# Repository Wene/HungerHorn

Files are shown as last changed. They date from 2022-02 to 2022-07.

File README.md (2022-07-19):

# HungerHorn

Once upon a time in a hackerspace far far away, on a Tuesday, everyone got hungry. And so it was decided to go hunt for a Pizza. The next Tuesday after that, they all got hungry again. But this time not everyone was in for the hunt right away. Apparently it was too early. Last week, so some commented, they all went at 19:00 o'clock. But yet it was just 18:55.
As social as the common hacker is, everyone waited patiently for the remaining 5 minutes before the hunt could begin. From this time on, the tradition was established. HungerTime™ is at precisely 19:00 o'clock.

Since this story is about a hackerspace, we naturally need to solve everything with technical measures. And so the project HungerHorn™ got started. It's supposed to sound an alarm signal at precisely HunterTime™. Since, nobody needs to stare at a watch the exciting minutes before.

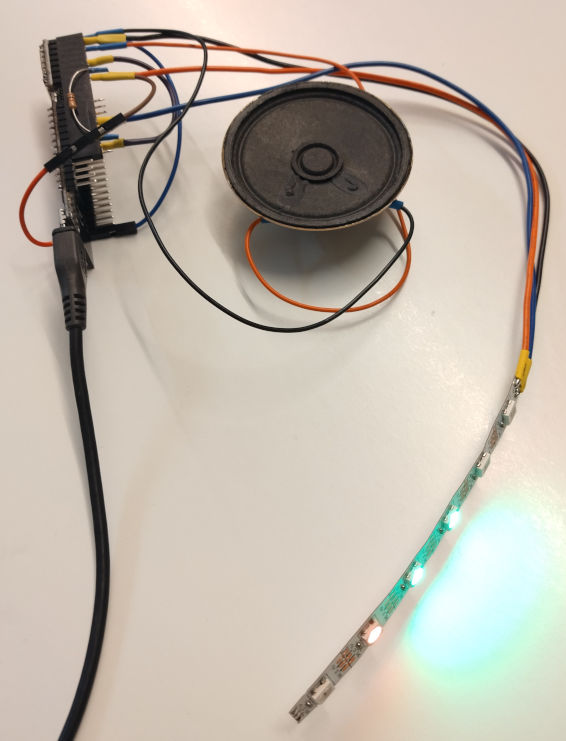
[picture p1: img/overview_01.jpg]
overview image


## Getting started

### Hardware
I'm using an ESP32 board called "WeMos LOLIN32 Lite". But any ESP32 should do. For the sound output a 0.3W PC speaker and a "DF Player mini" MP3 player module with a micro SD card is used. To display the time, I'm using a short strip of 6 WS2812B RGB LEDs.

### Software
The software is written using the PlatformIO toolkit. I use Qt Creator as source code editor, but I'm sure VS Code and others will also do.

After cloning the project, execute `platformio init --board lolin32_lite --ide qtcreator` in the project directory to initialize it. Adjust the command to your hardware board and IDE of choice. Then open the code in the `src/` directory and adjust the GPIOs or whatever needed for different hardware. Call `platformio run -t upload` to install it on your board.

### 3D Print
I've used the files in the `cad/` folder to 3D-print a case for the HungerHorn™. You will have to adjust several dimensions if you don't have exactly the same speaker and LED strip. To edit the 2D .dxf contours, I use LibreCAD. and the 3D models are OpenSCAD files.

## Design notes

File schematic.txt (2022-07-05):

┌─────────────────────────┬───────────────┐
│    ┌─────────┐          │               │
│  ┌─┤         ├───────┐  │  ┌──────────┐ │
│ ─┤ │         │  SPK2 ├──┼──┤ -        │ │
│  │ │ MicroSD │       │  │  │          │ │
│ ─┤ │         │   GND ├──┘  │  Speaker │ │
│  │ │         │       │     │          │ │
│ ─┤ │         │  SPK1 ├─────┤ +        │ │
│  │ └─────────┘       │     └──────────┘ │
│ ─┤                   ├─                 │
│  │ DF Player Mini    │               ┌──┘
│ ─┤                   ├─              │
│  │                   │               │
│ ─┤                TX ├────────────┐  │
│  │                   │            │  │
│ ─┤                RX ├───────┐    │  │
│  │                   │       │    │  │
│ ─┤               VCC ├──┐    │    │  │
│  └───────────────────┘  │ ┌──┴──┐ │  │
│                         │ │ 1kΩ │ │  │
│  ┌───────────────────┐  │ └──┬──┘ │  │
│ ─┤ VP            3v3 ├─ │    │    │  │
│  │                   │  │    │    │  │
│ ─┤ VN             22 ├─ │    │    │  │
│  │                   │  │    │    │  │ ┌─────────────────────────┐
│ ─┤ EN             19 ├─ │    │    │  └─┤ GND                     │
│  │      LOLIN32      │  │    │    │    │                         │
│ ─┤ 34   Lite      23 ├──┼────┼────┼────┤ DATA   6 × WS2812B LEDs │
│  │      ESP32        │  │    │    │    │                         │
│ ─┤ 35             18 ├─ ├────┼────┼────┤ 5V                      │
│  │                   │  │    │    │    └─────────────────────────┘
│ ─┤ 32              5 ├─ │    │    │
│  │                   │  │    │    │
│ ─┤ 33             17 ├──┼────┘    │
│  │                   │  │         │
│ ─┤ 25             16 ├──┼─────────┘
│  │                   │  │
│ ─┤ 26              4 ├─ │
│  │                   │  │
│ ─┤ 27              0 ├─ │
│  │                   │  │
│ ─┤ 14              2 ├─ │
│  │        5V         │  │
│ ─┤ 12     │       15 ├─ │
│  │        │          │  │
└──┤ GND    │       13 ├─ │
   └────────┼──────────┘  │
            └─────────────┘

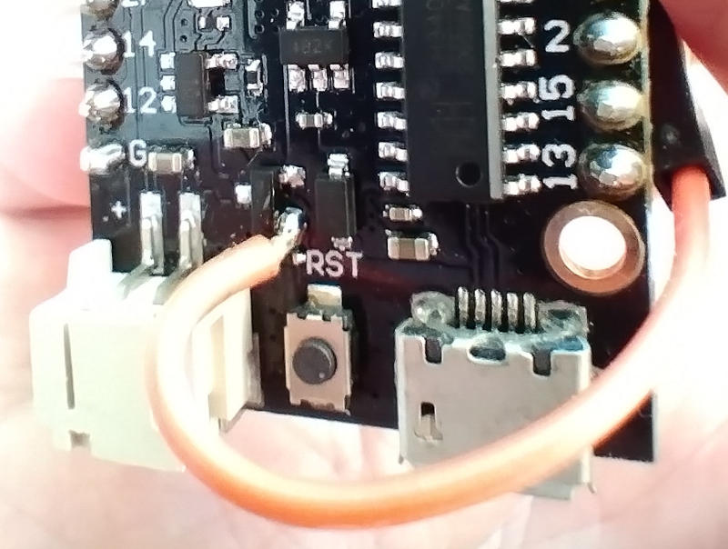
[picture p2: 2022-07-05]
img/5V_tap.jpg

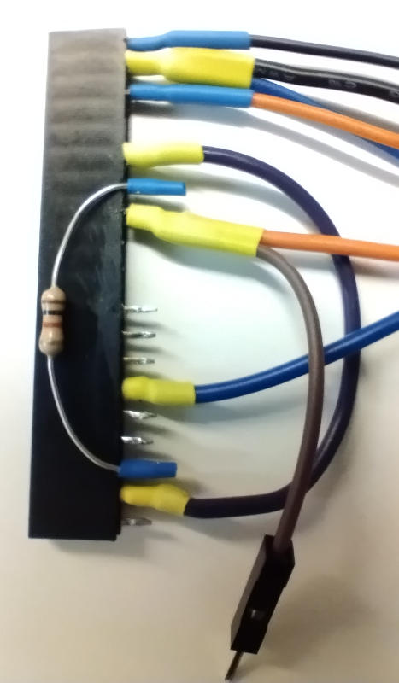
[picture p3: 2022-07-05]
img/connector_01.jpg

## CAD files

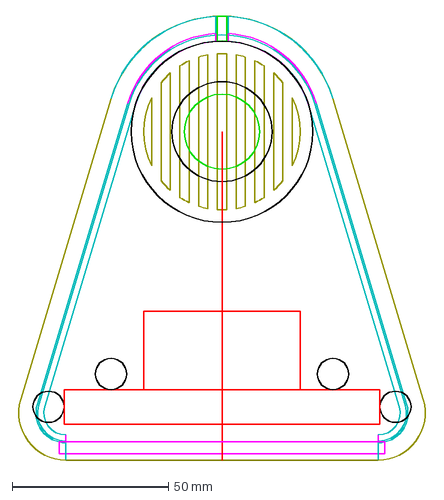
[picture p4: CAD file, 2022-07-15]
cad/case.dxf
131.5 x 142.0 mm

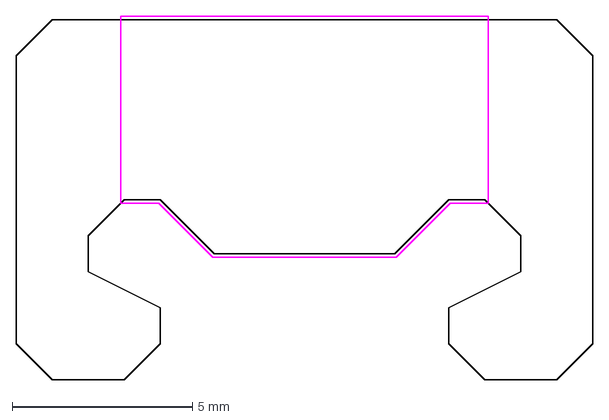
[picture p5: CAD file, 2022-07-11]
cad/led_holder.dxf
16.0 x 10.1 mm

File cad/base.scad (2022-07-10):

$fn = 100;

wall = 100/6;
speaker_height = 18;
speaker_base = 12;
support_height = wall - (speaker_height - speaker_base);

difference(){
    
    union(){
        translate([0,0,-3]){
            linear_extrude(height=3){
                import("case.dxf", layer="base");
            }
        }
        linear_extrude(height=wall){
            import("case.dxf", layer="base_wall");
        }
        linear_extrude(height=wall-5.5){
            import("case.dxf", layer="base_ridge");
            import("case.dxf", layer="led_holder");
        }
        linear_extrude(height=support_height){
            import("case.dxf", layer="speaker_support_out");
        }
    }
    
    translate([0,0,-2]){
        linear_extrude(height=wall+3){
            import("case.dxf", layer="groove");
        }
    }
    translate([0,0,support_height-speaker_base]){
        linear_extrude(height=speaker_base+0.1){
            import("case.dxf", layer="speaker_support_in");
        }
    }
}

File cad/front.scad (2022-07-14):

$fn = 100;

part=100/6;
border=3;
thick=3;
numbers = ["32", "16", "8", "4", "2", "1"];

difference(){
    translate([-border/2, -(part+border)/2, 0]){
        cube([6*part+border, part+border, thick]);
    }

    for(i = [0 : 1 : 5]){
        translate([i*part+part/2, 0, -0.1]){
            linear_extrude(thick-0.3+0.1){
                text(numbers[i], 8, valign="center", halign="center");
            }
        }
    }
}

for(dist = [part : part : 5*part]){
    translate([dist, 0, -3.5]){
        cube([1.5, part, 7], center=true);
    }
}

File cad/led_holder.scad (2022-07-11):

$fn = 100;

difference(){   
    linear_extrude(height=100){
        import("led_holder.dxf", layer="profile");
    }
    translate([0, 0, 97]){
        linear_extrude(height=3.1){
            import("led_holder.dxf", layer="cable");
        }
    }
}

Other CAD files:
cad/top.scad

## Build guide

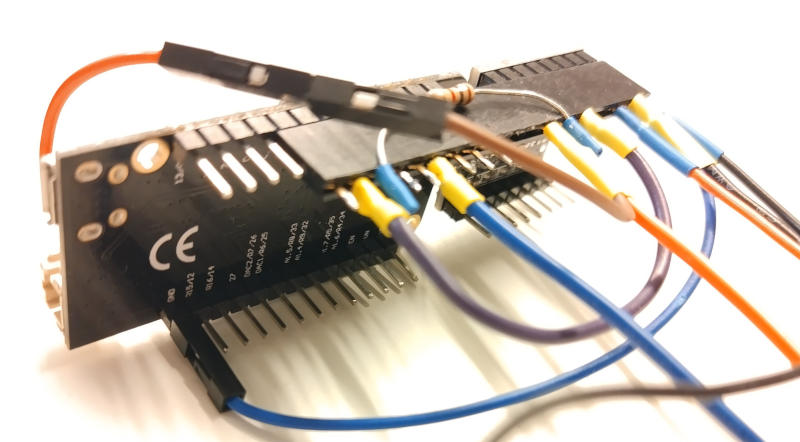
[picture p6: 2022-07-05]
img/assembly_02.jpg

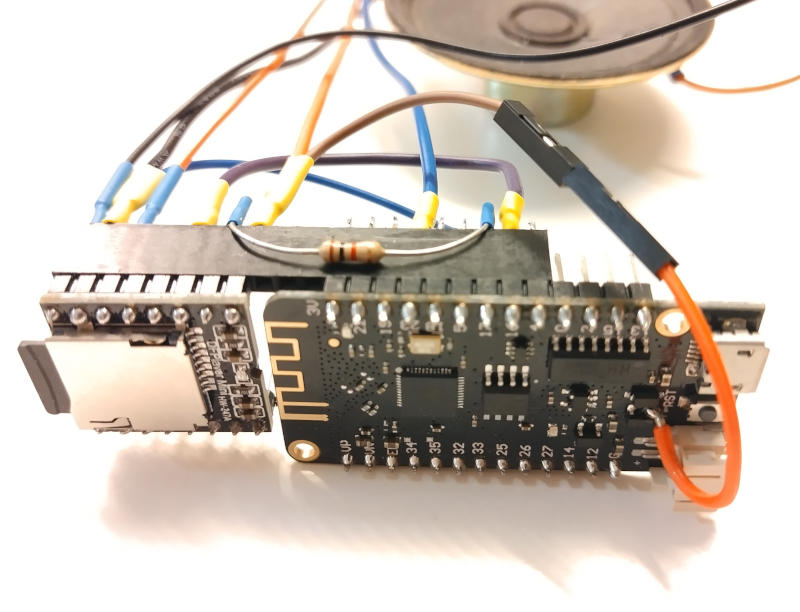
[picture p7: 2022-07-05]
img/assembly_01.jpg

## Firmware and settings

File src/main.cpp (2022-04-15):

#include <Arduino.h>
#include <WiFi.h>
#include <functional>

#include "player.h"
#include "terminal.h"
#include "network.h"
#include "alarmclock.h"
#include "lightshow.h"

static void menu_display();

static void menu_selection(const String &input)
{
  if(input == "w")
  {
    network.config_start();
  }
  else if(input == "c")
  {
    alarmclock.config_start();
  }
  else if(input == "a")
  {
    alarmclock.alarm_setup_start();
  }
  else if(input == "t")
  {
    alarmclock.print_time();
    menu_display();
  }
  else
  {
    Serial.print(F("Selection \""));
    Serial.print(input);
    Serial.println(F("\" not found."));
    menu_display();
  }
}

static void menu_display()
{
  Serial.println();
  Serial.println(F("Menu - enter the letter in front of the entry"));
  Serial.println(F("w - WiFi scan and configuration"));
  Serial.println(F("c - clock setup (NTP server, time zone)"));
  Serial.println(F("a - alarm time settings"));
  Serial.println(F("t - display the current time"));
  terminal.input(menu_selection);
}

void setup()
{
  terminal.setup(menu_display);
  lightshow.setup();
  network.setup();
  alarmclock.setup();
  player.setup();

  alarmclock.add_event_callback(std::bind(&Lightshow::event, &lightshow));

  Serial.println(F("Setup done."));
  menu_display();
}

void loop()
{
  unsigned long now = millis();
  terminal.tick(now);
  alarmclock.tick(now);
  lightshow.tick(now);
  network.tick(now);
  delay(1);
}

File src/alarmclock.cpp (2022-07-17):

#include "alarmclock.h"

#include <functional>
#include <time.h>
#include <Preferences.h>

#include "terminal.h"
#include "player.h"

static const char *alarm_time_prefix = "time_";
static const char *alarm_sound_prefix = "sound_";
static const char *ntp_name = "ntp";
static const char *tz_name = "tz";

int Alarm::hour()
{
  return secs_in_day / 3600;
}

int Alarm::min()
{
  int min_sec = secs_in_day % 3600;
  return min_sec / 60;
}

int Alarm::sec()
{
  int min_sec = secs_in_day % 3600;
  return min_sec % 60;
}

void Alarm::hour(int new_val)
{
  if(secs_in_day < 0)
  {
    secs_in_day = 0;
  }

  int hour = new_val;
  int rest = secs_in_day % 3600;
  int min = rest / 60;
  int sec = rest % 60;

  secs_in_day = hour * 3600 + min * 60 + sec;
}

void Alarm::min(int new_val)
{
  if(secs_in_day < 0)
  {
    secs_in_day = 0;
  }

  int hour = secs_in_day / 3600;
  int rest = secs_in_day % 3600;
  int min = new_val;
  int sec = rest % 60;

  secs_in_day = hour * 3600 + min * 60 + sec;
}

void Alarm::sec(int new_val)
{
  if(secs_in_day < 0)
  {
    secs_in_day = 0;
  }

  int hour = secs_in_day / 3600;
  int rest = secs_in_day % 3600;
  int min = rest / 60;
  int sec = new_val;

  secs_in_day = hour * 3600 + min * 60 + sec;
}

AlarmClock::AlarmClock(): ntp_server{"pool.ntp.org"}, settings{new Preferences}
{

}

AlarmClock::~AlarmClock()
{
  settings->end();
  delete settings;
}

void AlarmClock::setup()
{
  settings->begin("alarm");

  int index = 0;
  while(true)
  {
    String time_key(alarm_time_prefix);
    time_key += index;
    String sound_key(alarm_sound_prefix);
    sound_key += index;

    if(settings->isKey(time_key.c_str()) && settings->isKey(sound_key.c_str()))
    {
      Alarm alarm;
      alarm.secs_in_day = settings->getInt(time_key.c_str());
      alarm.sound = settings->getUChar(sound_key.c_str());
      alarm_list.push_back(alarm);
    }
    else
    {
      break;
    }

    index++;
  }

  if(settings->isKey(ntp_name))
  {
    ntp_server = settings->getString(ntp_name);
  }
  if(settings->isKey(tz_name))
  {
    tz_str = settings->getString(tz_name);
  }
  setup_time();
}

void AlarmClock::tick(unsigned long now)
{
  if(now >= last_update + 1000ul)
  {
    last_update = now;

    time_t clock = time(NULL);
    struct tm *timeinfo = localtime(&clock);
    int32_t now_secs = timeinfo->tm_hour * 3600 + timeinfo->tm_min * 60 + timeinfo->tm_sec;

    for(Alarm& alarm : alarm_list)
    {
      if(now_secs == alarm.secs_in_day && alarm.sound)
      {
        player.play_track(alarm.sound);

        for(auto& event : event_callbacks)
        {
          event();
        }

        last_update += 10000ul;
      }
    }
  }
}

void AlarmClock::config_start()
{
  Serial.print(F("The current NTP server address is \""));
  Serial.print(ntp_server);
  Serial.println("\"");
  Serial.print(F("Enter the new address or just hit enter to keep it: "));
  terminal.input(std::bind(&AlarmClock::config_ntp, this, std::placeholders::_1));
}

void AlarmClock::config_ntp(const String &input)
{
  if(!input.isEmpty())
  {
    ntp_server = input;
  }

  Serial.print(F("The current timezone is \""));
  Serial.print(tz_str);
  Serial.println("\"");
  Serial.println(F("Find your tomezone info here: https://github.com/nayarsystems/posix_tz_db/blob/master/zones.csv"));
  Serial.print(F("Enter a new timezome (like \"CET-1CEST,M3.5.0,M10.5.0/3\") or just hit enter to keep the value: "));
  terminal.input(std::bind(&AlarmClock::config_tz, this, std::placeholders::_1));
}

void AlarmClock::config_tz(const String &input)
{
  if(!input.isEmpty())
  {
    tz_str = input;
  }

  settings->putString(ntp_name, ntp_server);
  settings->putString(tz_name, tz_str);

  setup_time();
}

void AlarmClock::alarm_setup_start()
{
  Serial.println();
  Serial.println(F("No | Sound | Time"));

  int index = 0;
  for(Alarm& alarm : alarm_list)
  {
    String line{index++};
    line += "  : ";

    char c_str[10];
    snprintf(c_str, sizeof(c_str), "%-6d: ", alarm.sound);
    line += c_str;

    snprintf(c_str, sizeof(c_str), "%02d:%02d:%02d", alarm.hour(), alarm.min(), alarm.sec());
    line += c_str;

    Serial.println(line);
  }

  Serial.print(F("Enter a number to edit, 'a' to add a new entry, or hit enter to abort: "));
  terminal.input(std::bind(&AlarmClock::alarm_setup_no, this, std::placeholders::_1));
}

void AlarmClock::alarm_setup_no(const String &input)
{
  if(input.isEmpty())
  {
    return;
  }

  if(input == "a")
  {
    setup_index = alarm_list.size();
    alarm_list.emplace_back(Alarm{});
  }
  else
  {
    setup_index = input.toInt();
  }

  if(setup_index >= 0 && setup_index < alarm_list.size())
  {
    Serial.print(F("Enter the sound number or 'd' to delete this alarm: "));
    terminal.input(std::bind(&AlarmClock::alarm_setup_snd, this, std::placeholders::_1));
    setup_alarm = alarm_list[setup_index];
  }
  else
  {
    Serial.println(F("selection out of range"));
  }
}

void AlarmClock::alarm_setup_snd(const String &input)
{
  if(input.isEmpty())
  {
    return;
  }

  if(input == "d")
  {
    alarm_list.erase(alarm_list.begin() + setup_index);
    for(unsigned long i = setup_index; i < alarm_list.size(); i++)
    {
      Alarm& alarm = alarm_list[i];
      store_alarm(alarm, i);
    }
    String time_key(alarm_time_prefix);
    time_key += alarm_list.size();
    settings->remove(time_key.c_str());
    String sound_key(alarm_sound_prefix);
    sound_key += alarm_list.size();
    settings->remove(sound_key.c_str());
  }
  else
  {
    setup_alarm.sound = input.toInt();
    Serial.print(F("Enter the alarm time: "));
    terminal.input(std::bind(&AlarmClock::alarm_setup_time, this, std::placeholders::_1));
  }
}

void AlarmClock::alarm_setup_time(const String &input)
{
  if(!input.isEmpty())
  {
    int pos = input.indexOf(':');
    if(0 >= pos)
    {
      Serial.println(F("invalid format - abort"));
      return;
    }
    String hour_str = input.substring(0, pos);
    String rest = input.substring(pos+1);
    pos = rest.indexOf(':');
    String min_str, sec_str;
    if(0 >= pos)
    {
      min_str = rest;
    }
    else
    {
      min_str = rest.substring(0, pos);
      sec_str = rest.substring(pos+1);
    }

    setup_alarm.hour(hour_str.toInt());
    setup_alarm.min(min_str.toInt());
    setup_alarm.sec(sec_str.toInt());
  }

  alarm_list[setup_index] = setup_alarm;

  store_alarm(setup_alarm, setup_index);
}

void AlarmClock::print_time()
{
  time_t timestamp = time(NULL);
  struct tm *timeinfo = localtime(&timestamp);

  Serial.println(timeinfo, "%Y-%m-%d %H:%M:%S");
}

void AlarmClock::add_event_callback(std::function<void(void)> event)
{
  event_callbacks.push_back(event);
}
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

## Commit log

2022-01-30 get the wlan setup bodget together somehow
    [main.cpp]
2022-01-31 made myself a knot into the code somehow... it seems to be late already...
2022-02-01 switch to global objects
2022-02-14 filter out control characters
2022-02-19 fix bug in alarm settings
    [alarmclock.cpp]
2022-07-05 add box drawing schematic
2022-07-05 add images of the assembly
2022-07-10 add case cad files
    [base.scad, case.dxf, front.scad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]
2022-07-10 add led holder cad model
    [led_holder.dxf, led_holder.scad]
2022-07-10 improve cad models
    [base.scad, case.dxf, front.scad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]
2022-07-11 add groove for wires
    [led_holder.dxf, led_holder.scad]
2022-07-13 make intent more visible
    [top.scad]
2022-07-14 make front thicker for better readability
    [case.dxf, front.scad]
2022-07-15 add top indentation for the speaker
    [case.dxf, top.scad]
2022-07-15 reset player if no SD card was found
    [player.cpp]
2022-07-17 update gitignore for CAD files
2022-07-17 handle failed network scan
    [network.cpp]
2022-07-19 add description for the 3D prints
